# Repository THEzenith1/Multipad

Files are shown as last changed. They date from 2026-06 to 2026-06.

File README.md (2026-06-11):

# Multipad v1

A modular solution to make your workflow faster. Designed spesifically for video and code editing. 

(https://postimg.cc/XrVwQDB7)
## How it Works

Modules (M1,etc) slot into the two slots of the Hub (H2) magnetically and automatically connect to the attached computer. The modules are 100% hot swap. Extra expandability can be achived by attaching Stands (S1) to the bottom of the H2. These act as a host for the H2 and modules on it. (meaning when using the stand module plug your computer into the stand instead of the hub)
(https://postimg.cc/T5fwfB68)
## Features 

- QMK/VIA Compatability (M1,M1_RGB)

- Deej Compatability (https://github.com/omriharel/deej)

- Windows + MacOS Compatability (except M2) 
- Up to 2 Hot Swappable modules on H2
- Easy to expand usb interface in the 4 pin module interface
- Magnetic stands (S1) to expand multipad capability

## Current Modules

✅M1_RGB- A 12 key macropad with ARGB lights on keys 5-12 and VIA support (this is sometimes refured to in the docs as M3)

✅M2- 4 Volume sliders running the deej firmwere

✅M4- A scrol wheel with 4 keys for davinchi resolve (Not VIA compatable. Key configuration in the aurduino file)

✅M5- Coster

✅S1- Attaches to the back of H2 to add 3 USB-C ports 

🚧S2- Adds a battery and wireless capabilities to the entire Multipad system

🚧M6- Spotify song viewer and media control with a screen

❌M1- An 11 key macropad with VIA support (depreciated module with 1st gen pcb)

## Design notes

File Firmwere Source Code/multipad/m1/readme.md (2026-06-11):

# multipad/m1

multipad/m1

*A short description of the keyboard/project*

* Keyboard Maintainer: [Owen](https://github.com/THEzenith1)
* Hardware Supported: *The PCBs, controllers supported*
* Hardware Availability: *Links to where you can find this hardware*

Make example for this keyboard (after setting up your build environment):

    make multipad/m1:default

Flashing example for this keyboard:

    make multipad/m1:default:flash

See the [build environment setup](https://docs.qmk.fm/#/getting_started_build_tools) and the [make instructions](https://docs.qmk.fm/#/getting_started_make_guide) for more information. Brand new to QMK? Start with our [Complete Newbs Guide](https://docs.qmk.fm/#/newbs).

## Bootloader

Enter the bootloader in 3 ways:

* **Bootmagic reset**: Hold down the key at (0,0) in the matrix (usually the top left key or Escape) and plug in the keyboard
* **Physical reset button**: Briefly press the button on the back of the PCB - some may have pads you must short instead
* **Keycode in layout**: Press the key mapped to `QK_BOOT` if it is available

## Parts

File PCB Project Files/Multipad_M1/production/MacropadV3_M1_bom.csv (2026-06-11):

Designator | Footprint | Quantity | Value | LCSC Part #
D1, D10, D11, D12, D2, D3, D4, D5, D6, D7, D8, D9 | Diode_DO-35 | 12 | ~
S1, S10, S11, S12, S2, S3, S4, S5, S6, S7, S8, S9 | MX_PCB_1.00u | 12 | ~
U2 | Adafruit_QTPY_2040 | 1 | ~

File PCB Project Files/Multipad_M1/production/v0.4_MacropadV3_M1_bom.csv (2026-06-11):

Designator | Footprint | Quantity | Value | LCSC Part #
D1, D10, D11, D12, D2, D3, D5, D6, D7, D8, D9 | Diode_DO-35 | 11 | ~
S1, S10, S11, S12, S2, S3, S5, S6, S7, S8, S9 | Choc_V1V2_1.00u | 11 | ~
U1 | Seeed_XIAO_RP2040 | 1 | MCU_Seeed_XIAO_RP2040

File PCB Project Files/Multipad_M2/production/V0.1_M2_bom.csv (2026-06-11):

Designator | Footprint | Quantity | Value | LCSC Part #
R1, R2, R3, R4 | TRIM_PTA4543-2015DPB103 | 4 | PTA4543-2015DPB103
U1 | Seeed_XIAO_RP2040 | 1 | MCU_Seeed_XIAO_RP2040

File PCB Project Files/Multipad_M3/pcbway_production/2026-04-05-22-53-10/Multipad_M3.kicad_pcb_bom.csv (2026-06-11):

Designator | Quantity | Value | Footprint | Package | MPN | DNP | Mount_Type
D1, D10, D11, D12, D2, D3, D4, D5, D6, D7, D8, D9 | 12 | ~ | Diode_DO-35 |  |  |  | tht
S1, S10, S11, S12, S2, S3, S4, S5, S6, S7, S8, S9 | 12 | ~ | Choc_V1V2_1.00u |  |  |  | tht
U1 | 1 | MCU_Seeed_XIAO_RP2040 | Seeed_XIAO_RP2040 |  |  |  | tht

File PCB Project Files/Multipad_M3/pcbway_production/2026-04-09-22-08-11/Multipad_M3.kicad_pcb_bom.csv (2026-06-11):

Designator | Quantity | Value | Footprint | Package | MPN | DNP | Mount_Type | Description | LCSC
D1, D10, D11, D12, D2, D3, D4, D5, D6, D7, D8, D9 | 12 | ~ | Diode_DO-35 |  |  |  | tht
LED1, LED2, LED3, LED4, LED5, LED6, LED7, LED8 | 8 | LED_SK6812MINI | LED_SK6812MINI |  |  |  | tht | RGB LED with integrated controller | C5149201
S1, S10, S11, S12, S2, S3, S4, S5, S6, S7, S8, S9 | 12 | ~ | Choc_V1V2_1.00u |  |  |  | tht
U1 | 1 | MCU_Seeed_XIAO_RP2040 | Seeed_XIAO_RP2040 |  |  |  | tht

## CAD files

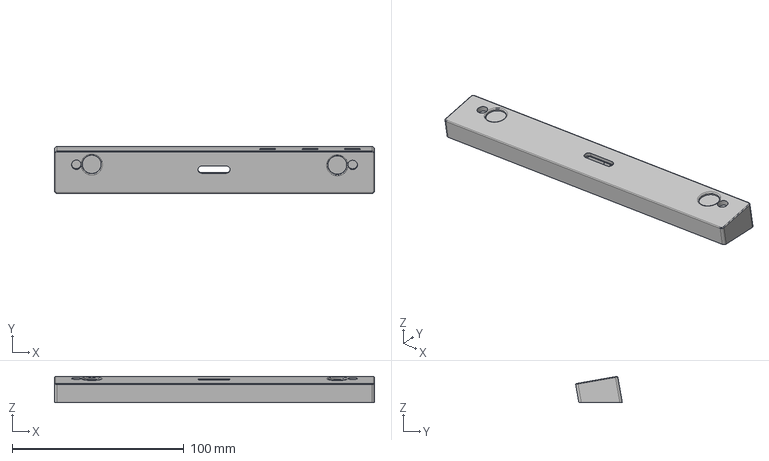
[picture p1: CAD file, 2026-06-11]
CAD Exports/S1_MainHousing.step
186.5 x 27.3 x 15.3 mm

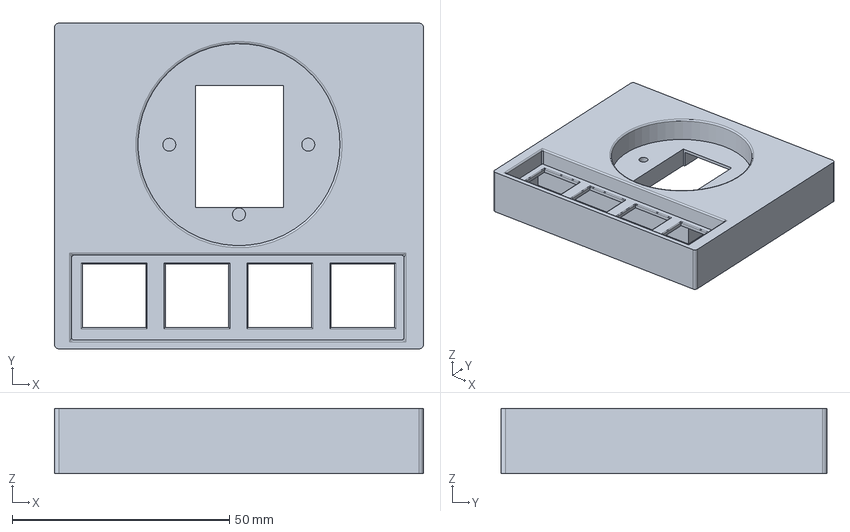
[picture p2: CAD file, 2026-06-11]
CAD Exports/M4_MainHousing.step
85.0 x 75.0 x 15.0 mm

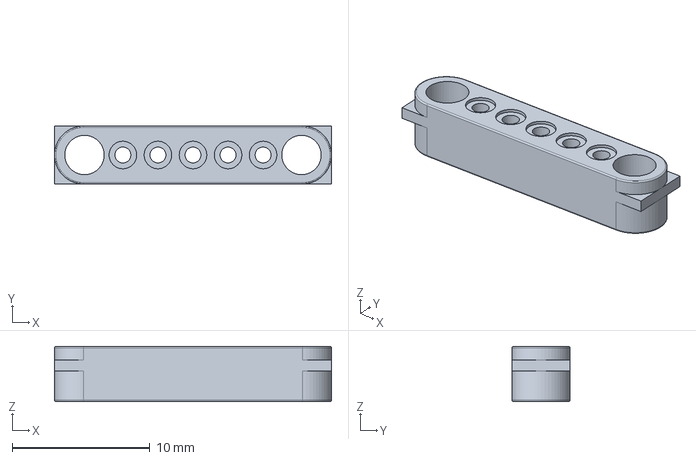
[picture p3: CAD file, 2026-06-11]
CAD Exports/H2_MainHousing.step
20.1 x 4.20 x 4.00 mm

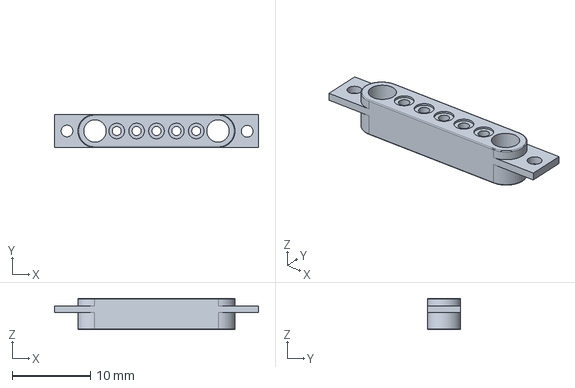
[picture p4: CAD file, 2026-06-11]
CAD Exports/MTemplate_MainHousing.step
26.1 x 4.20 x 4.00 mm

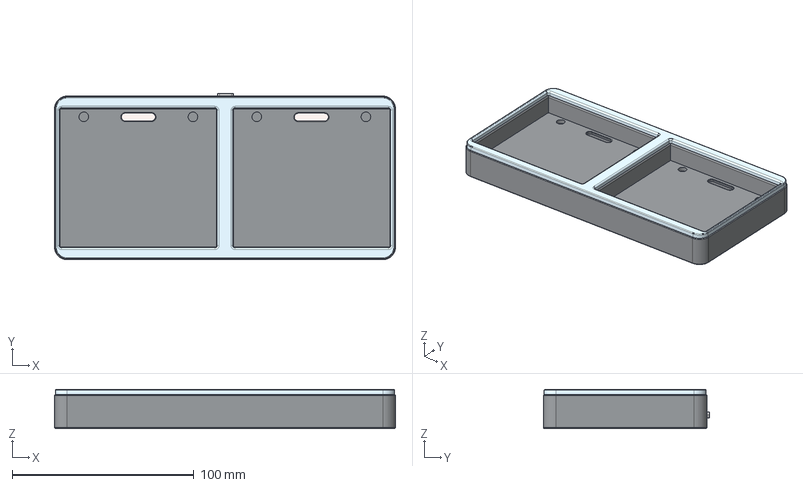
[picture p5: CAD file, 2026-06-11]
CAD Exports/H2_Assembly.step
187.5 x 91.5 x 21.7 mm

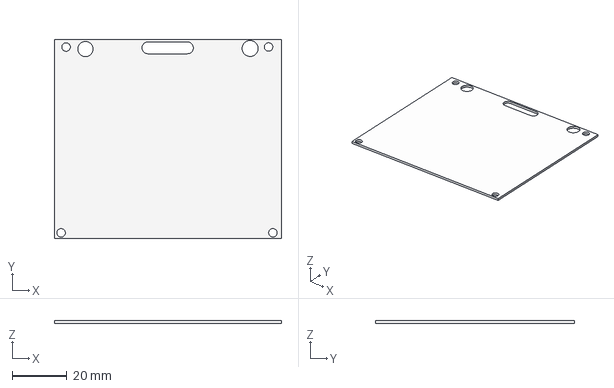
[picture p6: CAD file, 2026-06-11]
CAD Exports/M4_BottomPlate.step
82.6 x 72.2 x 1.00 mm

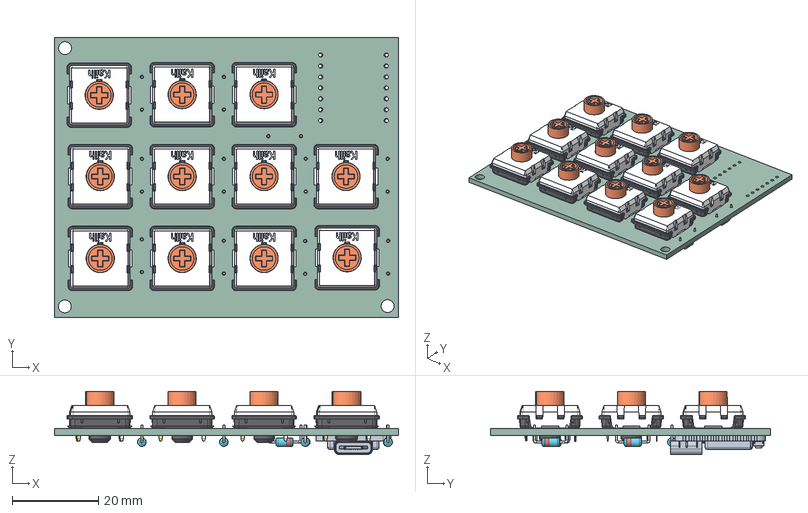
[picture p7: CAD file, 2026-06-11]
PCB Project Files/Multipad_M1/v_0.3Multipad_M1.step
80.0 x 65.0 x 14.7 mm
red x 11
D_DO-35_SOD27_P7.62mm_Horizontal x 11
Seeed Studio XIAO RP2040 v26
_autosave-Multipad_M1_PCB

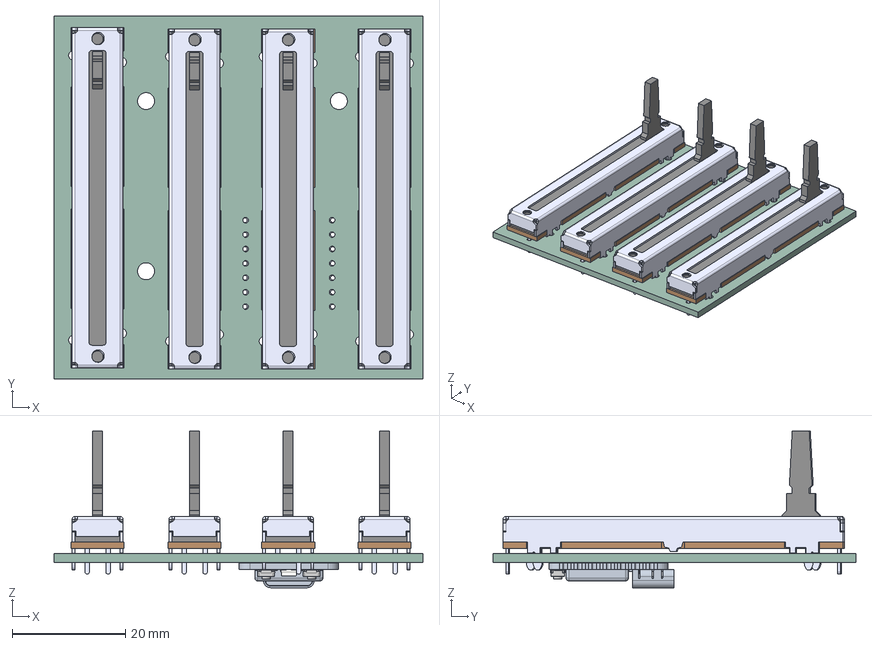
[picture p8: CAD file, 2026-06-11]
PCB Project Files/Multipad_M2/v0.1_Multipad_M2.step
65.0 x 64.0 x 27.6 mm
45315DP x 4
Seeed Studio XIAO RP2040 v26
Multipad_M2_PCB

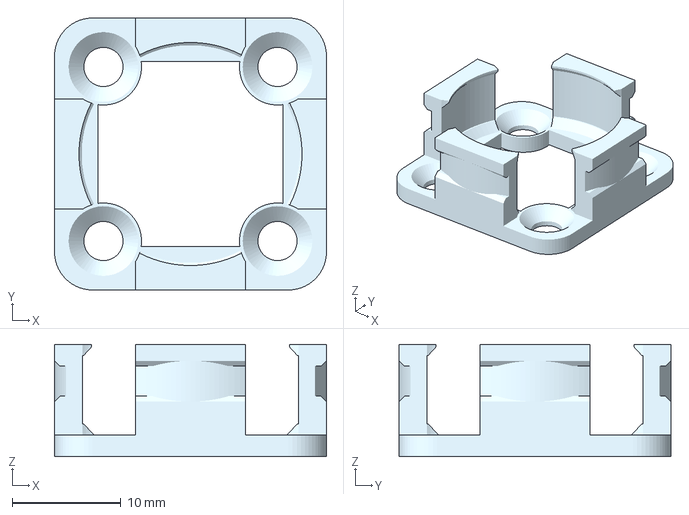
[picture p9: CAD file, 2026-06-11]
CAD Exports/M4_WheelBaringHolder.step
25.0 x 25.0 x 10.3 mm

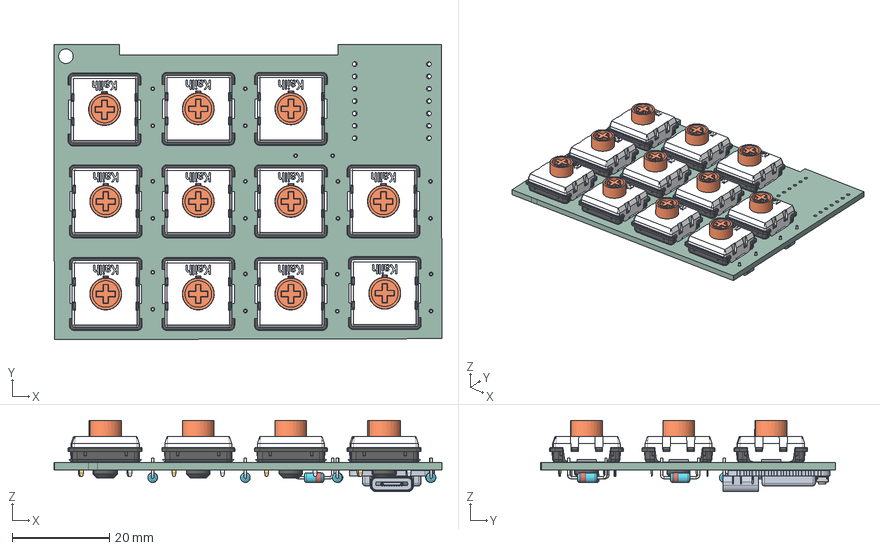
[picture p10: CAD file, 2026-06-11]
PCB Project Files/Multipad_M1/v_0.4Multipad_M1.step
79.8 x 60.8 x 14.7 mm
red x 11
D_DO-35_SOD27_P7.62mm_Horizontal x 11
Seeed Studio XIAO RP2040 v26
Multipad_M1_PCB

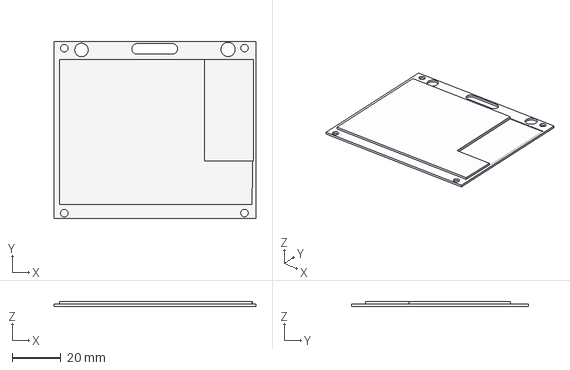
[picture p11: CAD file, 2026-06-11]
CAD Exports/MTemplate_BottomPlate.step
82.6 x 72.2 x 2.00 mm

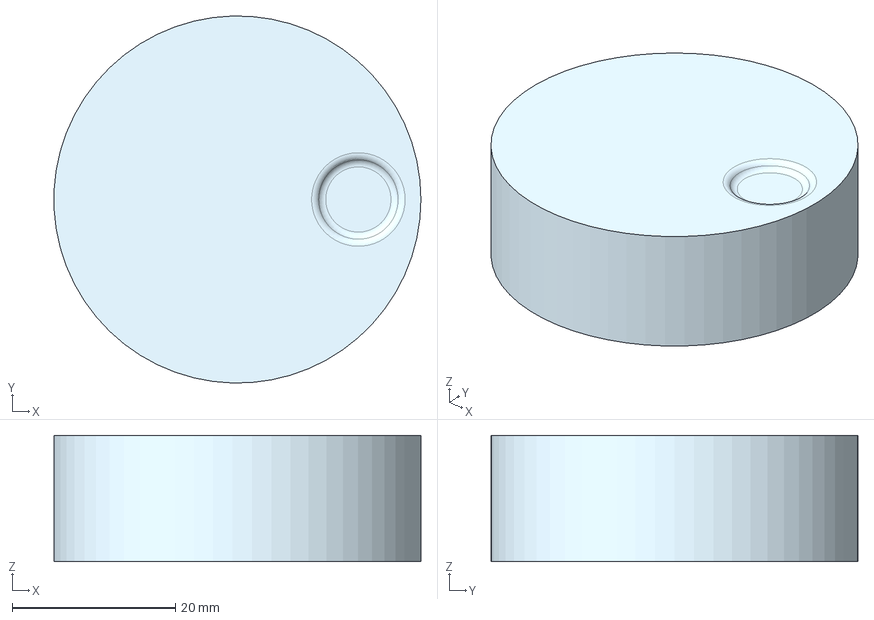
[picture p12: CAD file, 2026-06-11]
CAD Exports/M4_Wheel.step
45.0 x 45.0 x 15.5 mm

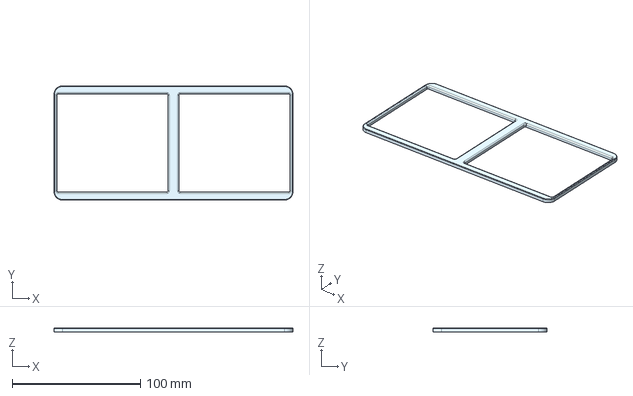
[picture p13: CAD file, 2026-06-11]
CAD Exports/H2_BeautyPlate.step
186.5 x 89.0 x 3.00 mm

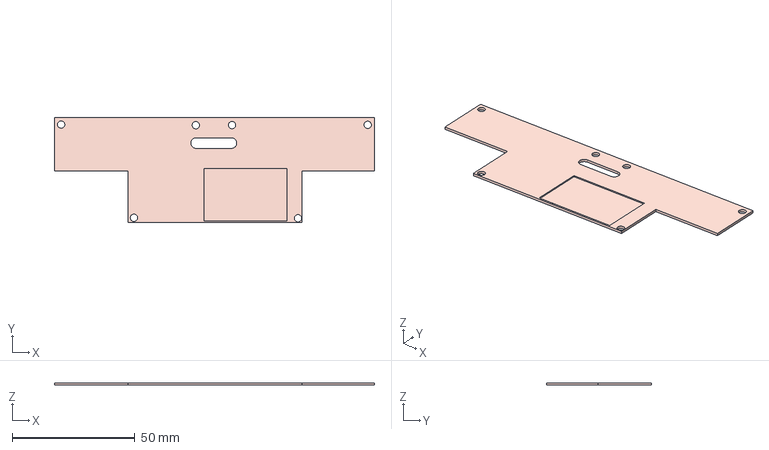
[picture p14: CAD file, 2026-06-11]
CAD Exports/H2_BottomPlate.step
130.4 x 42.8 x 1.00 mm

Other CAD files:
CAD Exports/M2_BottomPlate.step
CAD Exports/M1_FrontHousingKeyholder.step
CAD Exports/M1_BottomPlate.step
CAD Exports/M2_FrontHousing.step
CAD Exports/M4_WheelBaseplate.step
CAD Exports/M5_Cupholder.step
CAD Exports/S1_BottomPlate.step

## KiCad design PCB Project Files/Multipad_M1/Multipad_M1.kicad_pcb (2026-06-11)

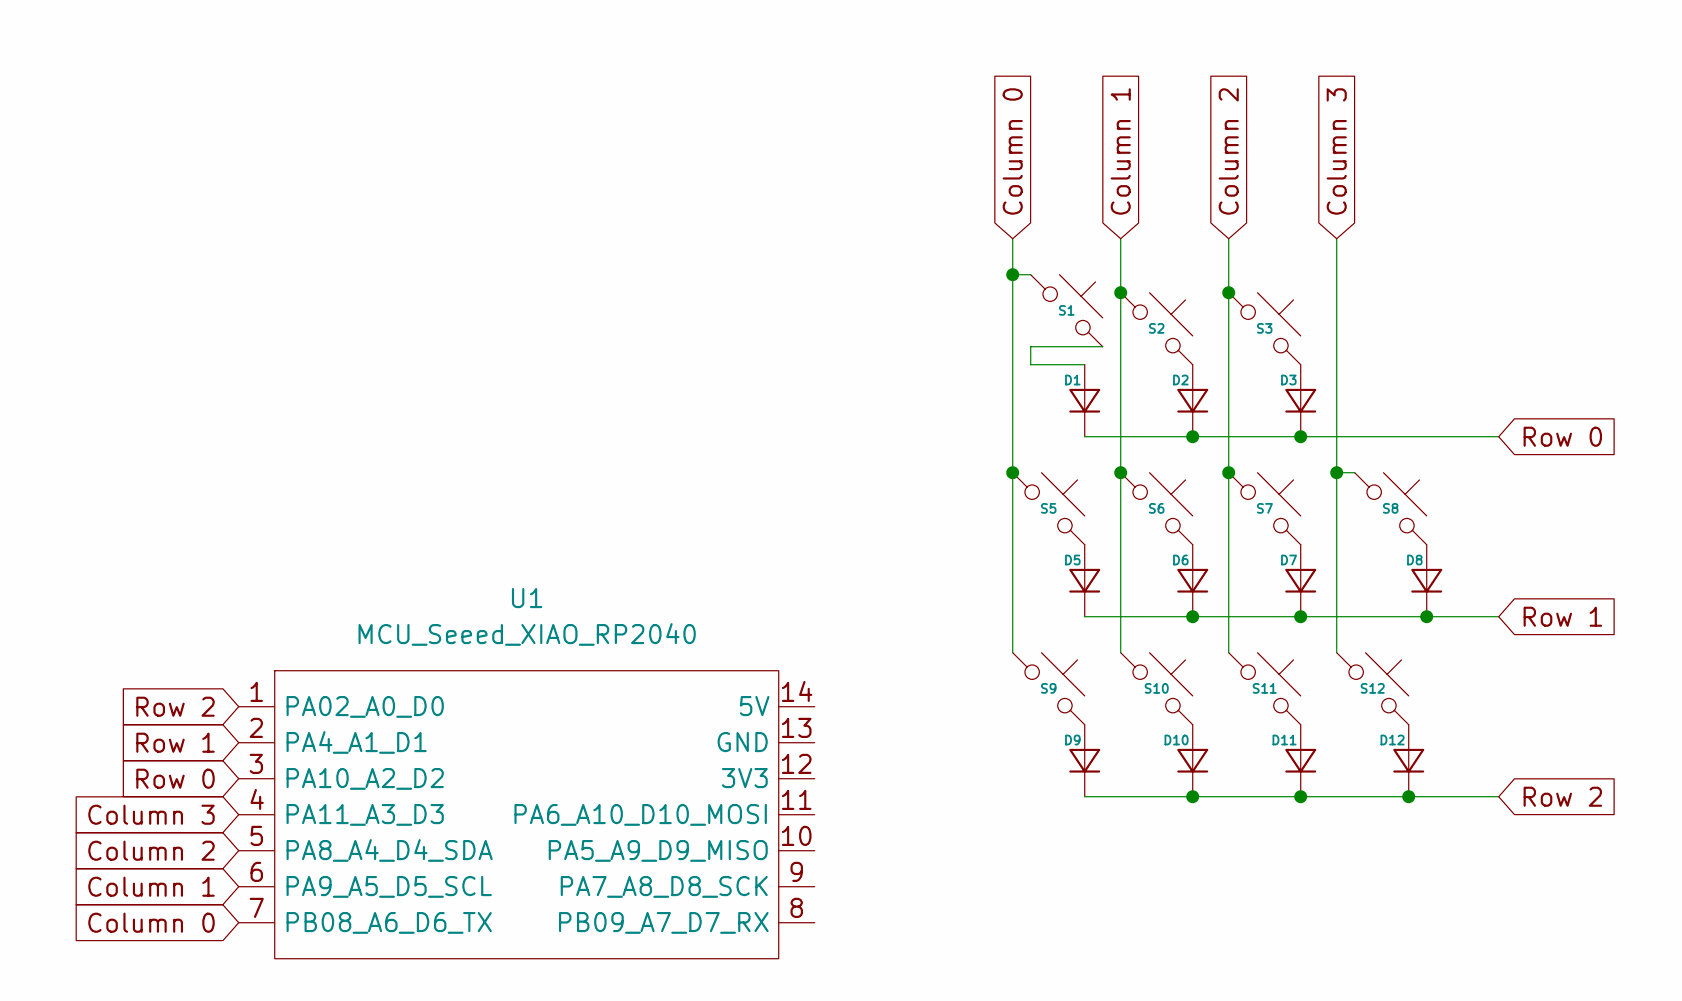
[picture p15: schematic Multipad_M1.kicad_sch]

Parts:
D1, D2, D3, D5, D6, D7, D8, D9, D10, D11, D12: Diode_DO-35
S1, S2, S3, S5, S6, S7, S8, S9, S10, S11, S12: Choc_V1V2_1.00u
U1: MCU_Seeed_XIAO_RP2040; Seeed_XIAO_RP2040

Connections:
Column 0: S1.1, S5.1, S9.1, U1.7 (PB08_A6_D6_TX)
Column 1: S2.1, S6.1, S10.1, U1.6 (PA9_A5_D5_SCL)
Column 2: S3.1, S7.1, S11.1, U1.5 (PA8_A4_D4_SDA)
Column 3: S8.1, S12.1, U1.4 (PA11_A3_D3)
unnamed: D1.2 (A), S1.2
unnamed: D2.2 (A), S2.2
unnamed: D3.2 (A), S3.2
unnamed: D5.2 (A), S5.2
unnamed: D6.2 (A), S6.2
unnamed: D7.2 (A), S7.2
unnamed: D8.2 (A), S8.2
unnamed: D9.2 (A), S9.2
unnamed: D10.2 (A), S10.2
unnamed: D11.2 (A), S11.2
unnamed: D12.2 (A), S12.2
Row 0: D1.1 (K), D2.1 (K), D3.1 (K), U1.3 (PA10_A2_D2)
Row 1: D5.1 (K), D6.1 (K), D7.1 (K), D8.1 (K), U1.2 (PA4_A1_D1)
Row 2: D9.1 (K), D10.1 (K), D11.1 (K), D12.1 (K), U1.1 (PA02_A0_D0)

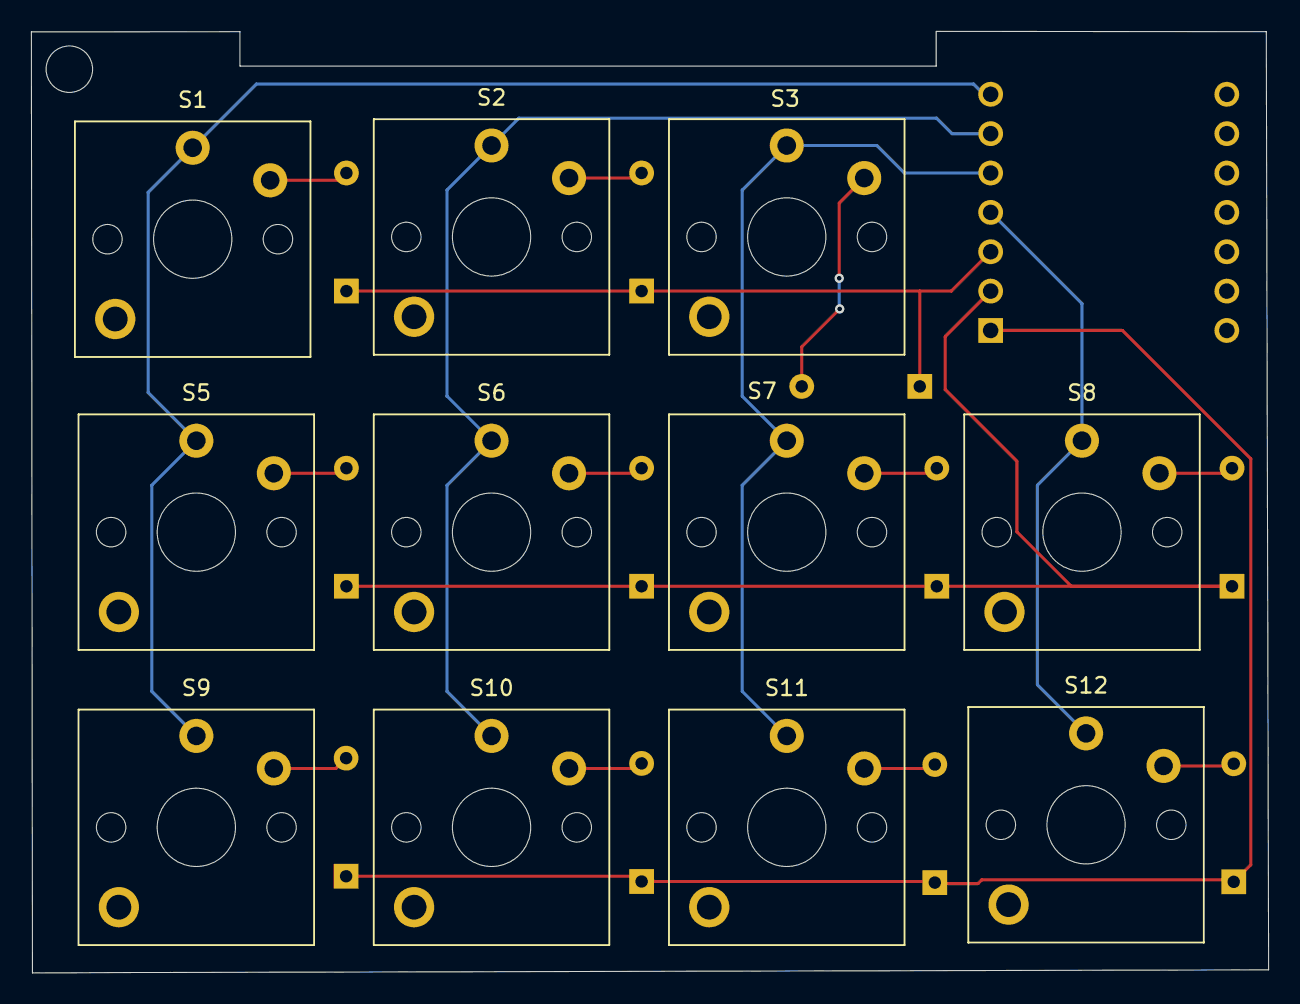
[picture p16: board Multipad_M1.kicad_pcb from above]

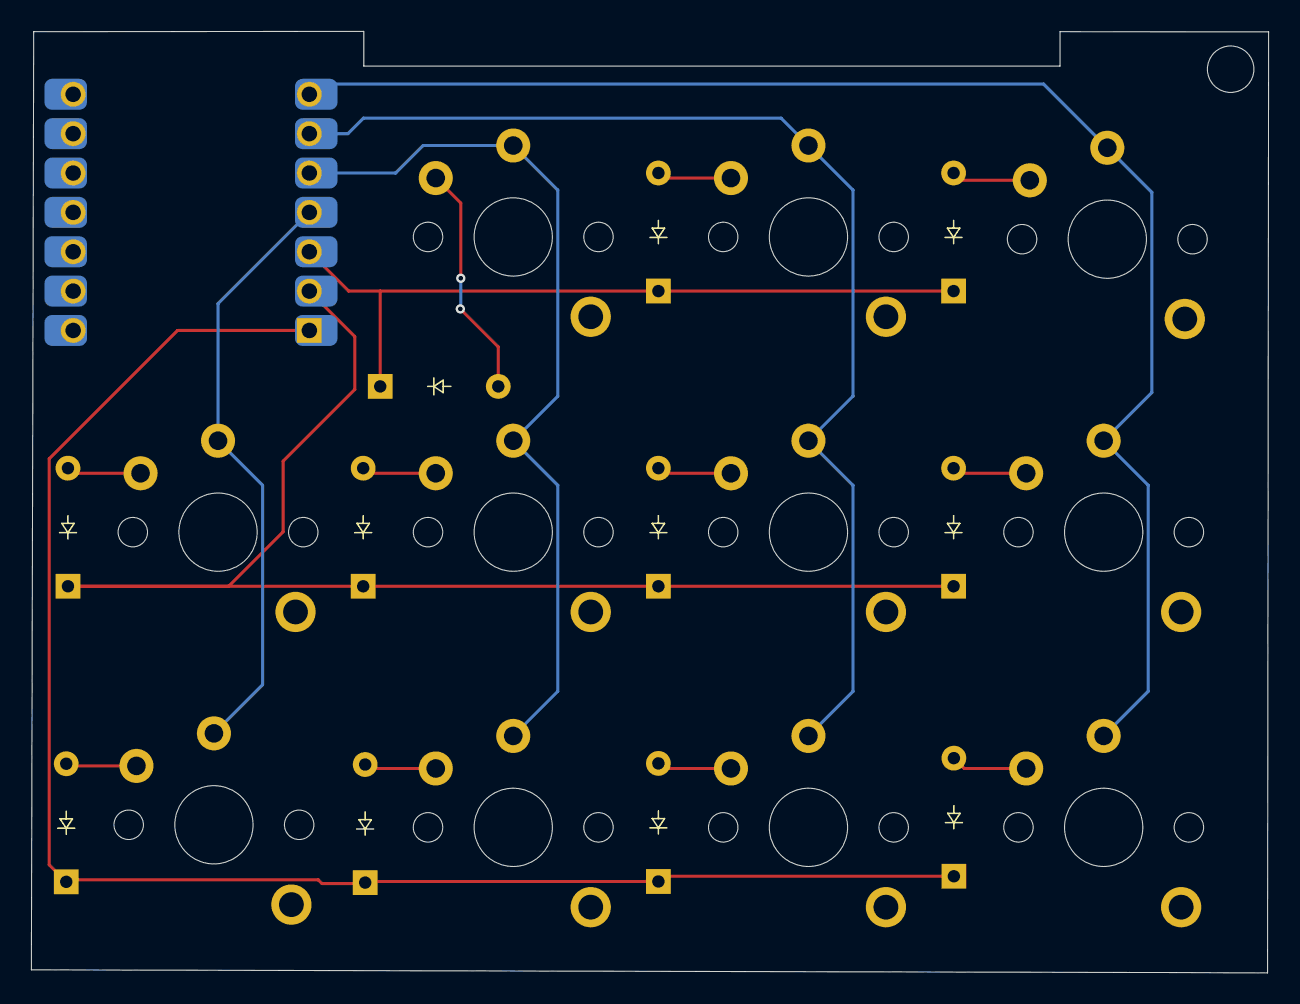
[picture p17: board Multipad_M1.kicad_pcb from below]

Board: 2 copper layers, 79.8 x 60.8 mm, 23 parts (12 on the bottom side), 18 nets.

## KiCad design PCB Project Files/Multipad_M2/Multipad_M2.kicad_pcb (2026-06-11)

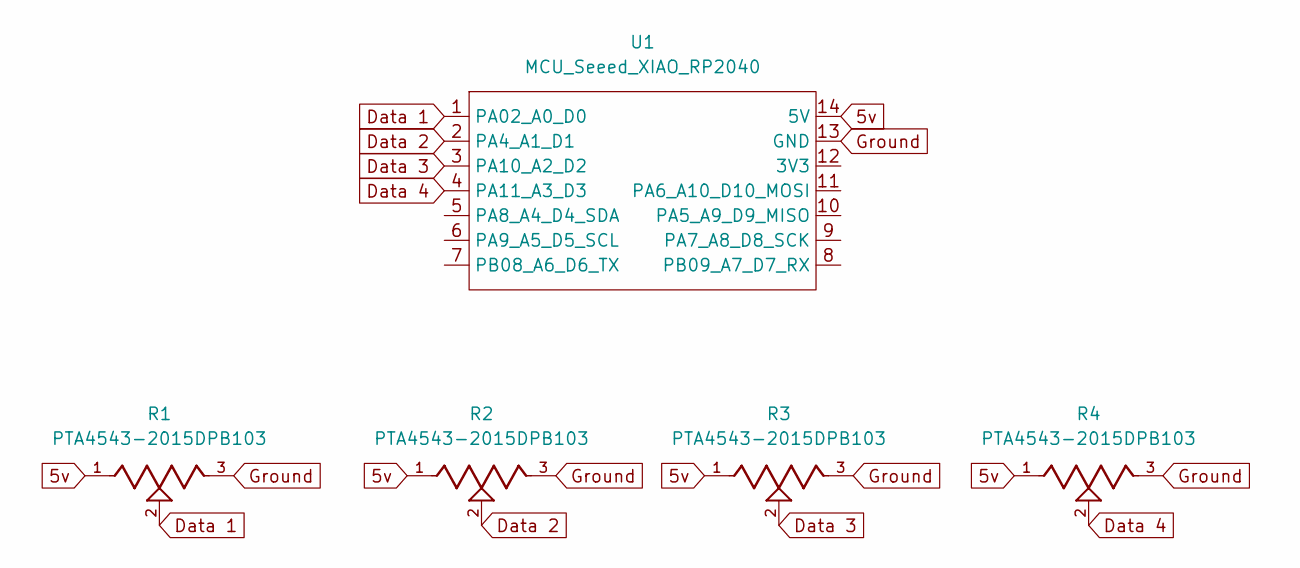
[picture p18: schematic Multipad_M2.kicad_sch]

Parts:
R1, R2, R3, R4: PTA4543-2015DPB103; TRIM_PTA4543-2015DPB103; PARTREV 04/21
U1: MCU_Seeed_XIAO_RP2040; Seeed_XIAO_RP2040

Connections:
5v: R1.1, R2.1, R3.1, R4.1, U1.14 (5V)
Data 1: R1.2, U1.1 (PA02_A0_D0)
Data 2: R2.2, U1.2 (PA4_A1_D1)
Data 3: R3.2, U1.3 (PA10_A2_D2)
Data 4: R4.2, U1.4 (PA11_A3_D3)
Ground: R1.3, R2.3, R3.3, R4.3, U1.13 (GND)

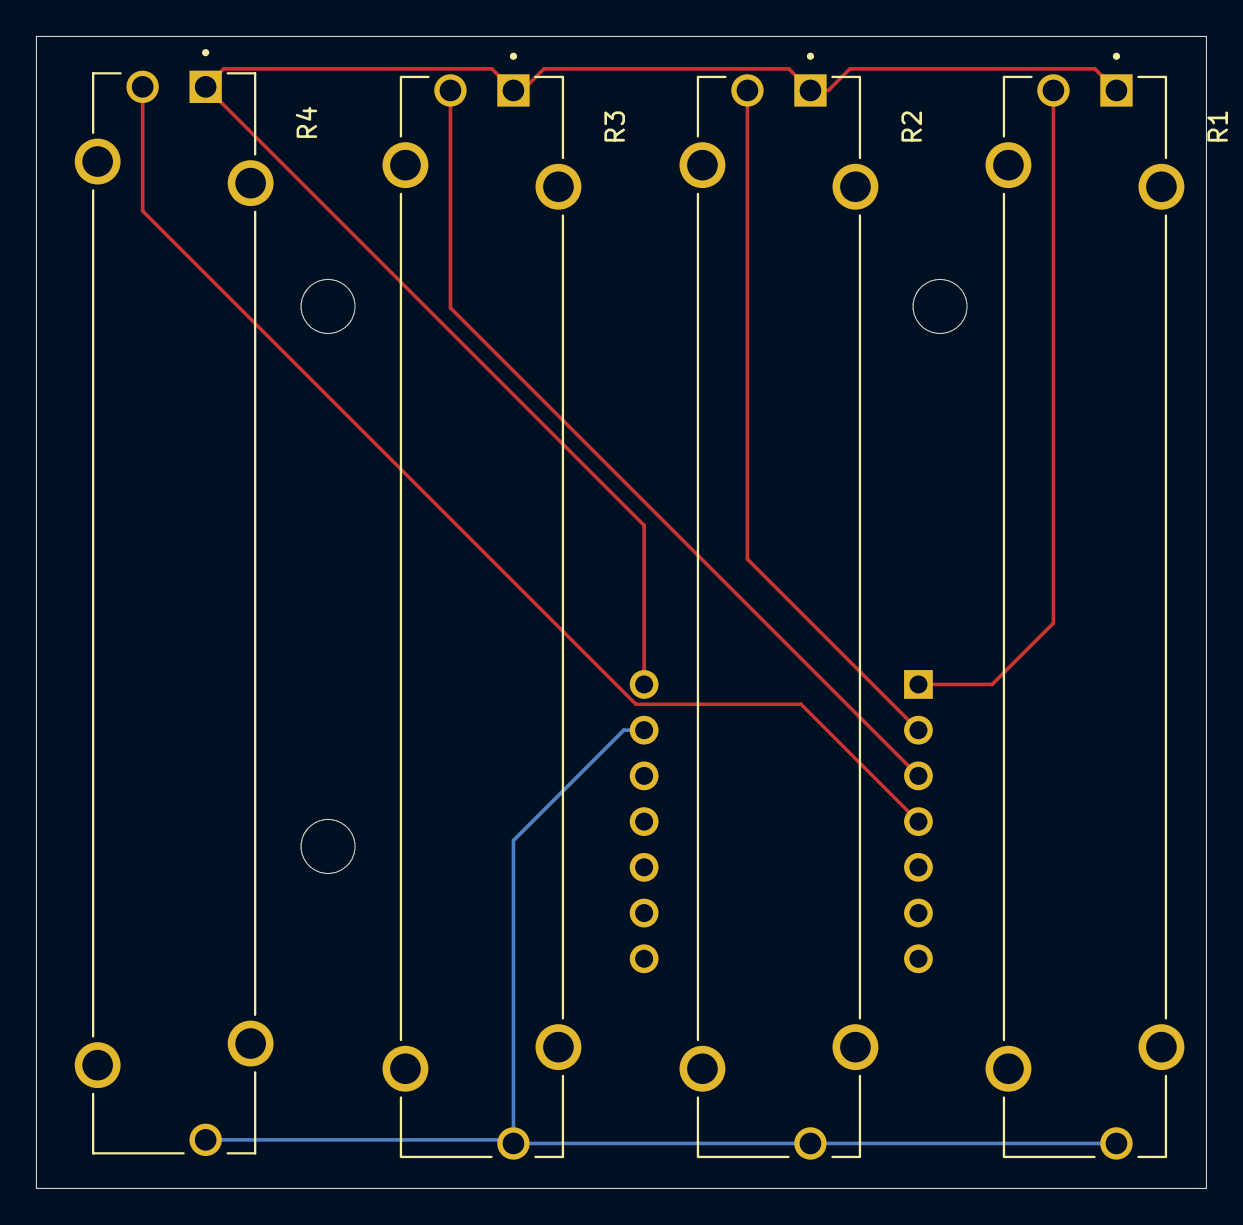
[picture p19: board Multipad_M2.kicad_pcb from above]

Board: 2 copper layers, 65.0 x 64.0 mm, 5 parts (1 on the bottom side), 6 nets.
